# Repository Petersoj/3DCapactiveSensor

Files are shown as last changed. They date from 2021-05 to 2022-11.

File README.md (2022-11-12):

# 3DCapacitiveSensor

This project uses the STM32F072RB MCU on the 32F072BDISCOVERY board and a large "3D" capacitor to measure the XYZ coordinates of a user's hand in physical space so that a user can move/click a computer mouse without touching anything. This project was inspired by [this](https://www.youtube.com/watch?v=ikD_3Vemkf0) video.

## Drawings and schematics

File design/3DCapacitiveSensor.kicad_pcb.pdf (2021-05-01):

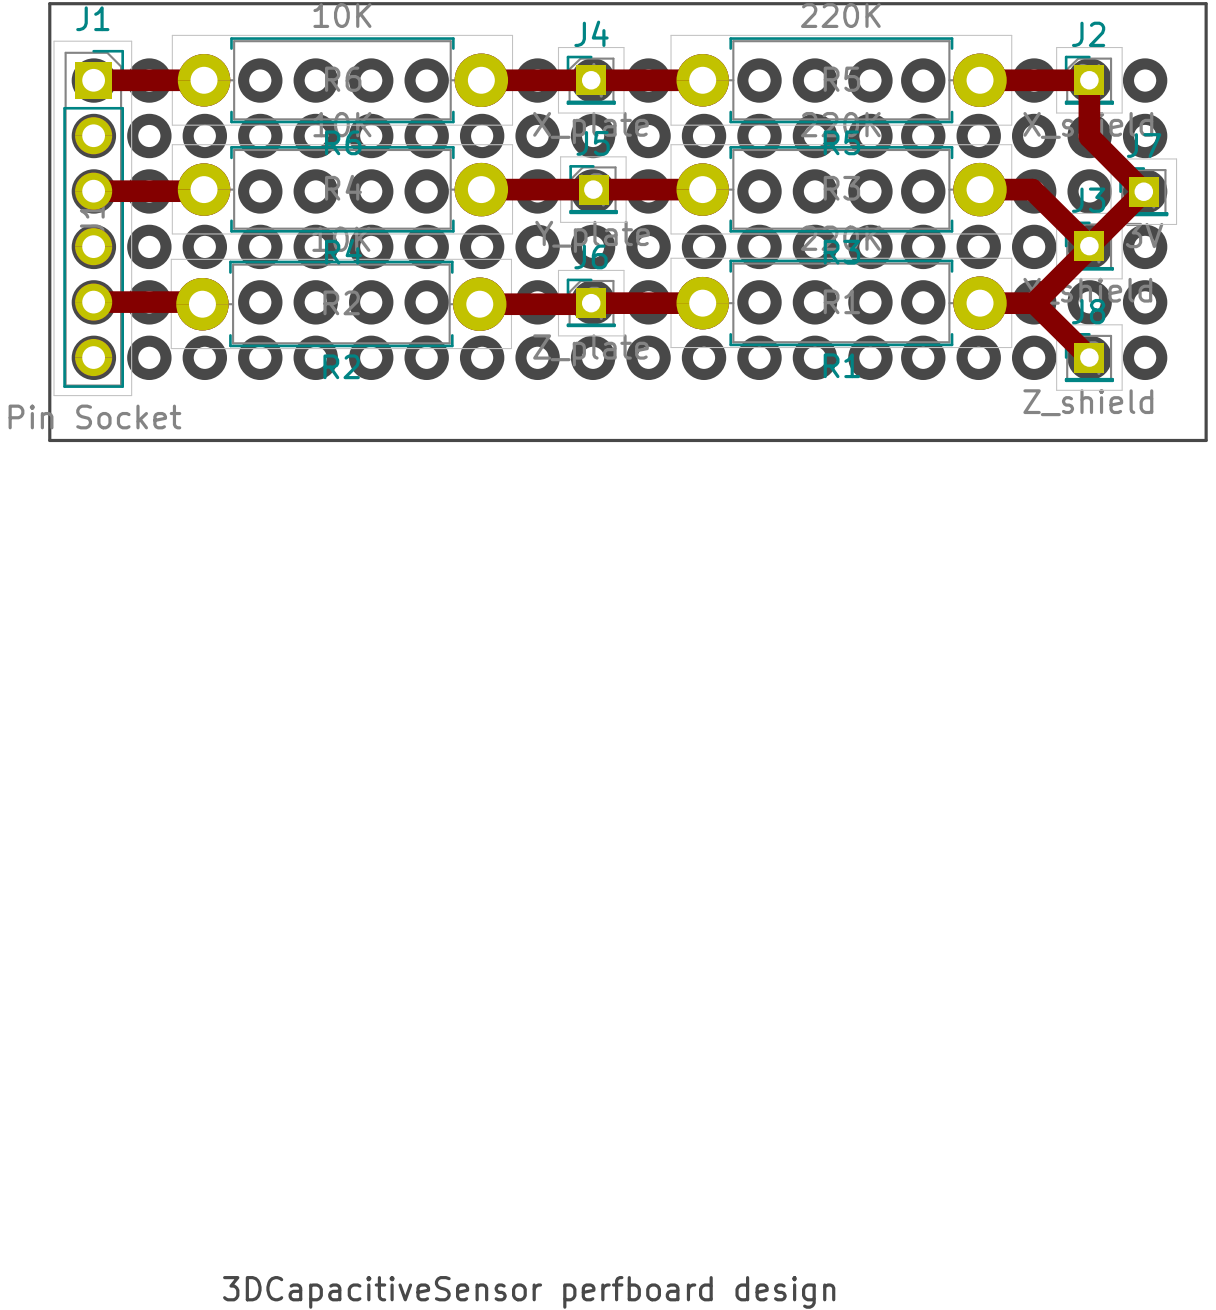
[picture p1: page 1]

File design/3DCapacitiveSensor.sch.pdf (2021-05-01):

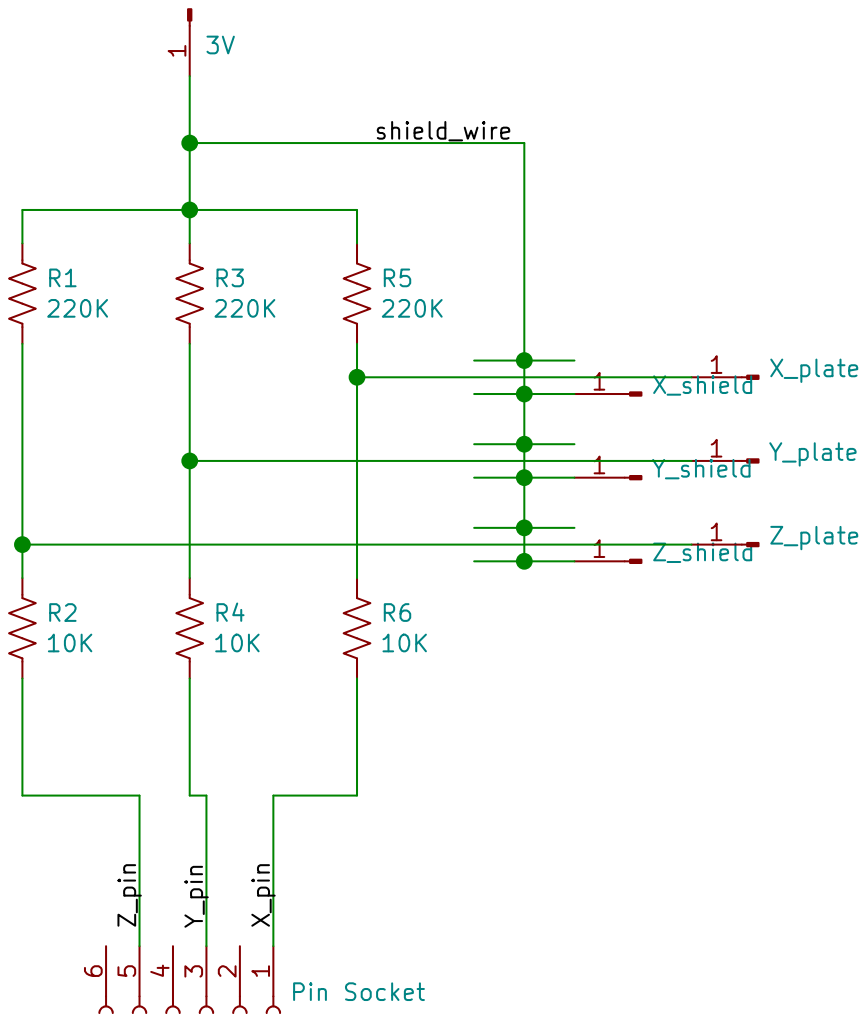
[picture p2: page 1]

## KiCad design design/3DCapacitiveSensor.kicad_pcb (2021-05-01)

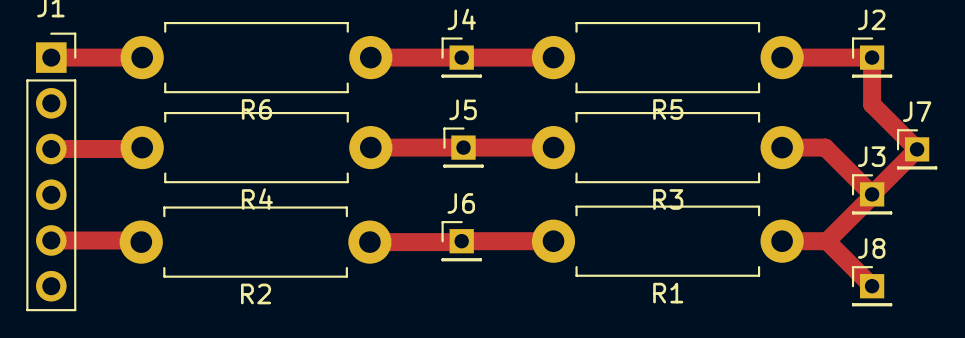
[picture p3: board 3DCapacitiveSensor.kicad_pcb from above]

Board: 2 copper layers, 14 parts (0 on the bottom side), 7 nets.

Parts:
J1: Pin Socket; PinSocket_1x06_P2.54mm_Vertical
J2: X_shield; PinHeader_1x01_P2.00mm_Vertical
J3: Y_shield; PinHeader_1x01_P2.00mm_Vertical
J4: X_plate; PinHeader_1x01_P2.00mm_Vertical
J5: Y_plate; PinHeader_1x01_P2.00mm_Vertical
J6: Z_plate; PinHeader_1x01_P2.00mm_Vertical
J7: 3V; PinHeader_1x01_P2.00mm_Vertical
J8: Z_shield; PinHeader_1x01_P2.00mm_Vertical
R1, R3, R5: 220K; R_Axial_DIN0411_L9.9mm_D3.6mm_P12.70mm_Horizontal
R2, R4, R6: 10K; R_Axial_DIN0411_L9.9mm_D3.6mm_P12.70mm_Horizontal

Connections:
/X_pin: J1.1, R6.2
/Y_pin: J1.3, R4.2
/Z_pin: J1.5, R2.2
/shield_wire: J2.1, J3.1, J7.1, J8.1, R1.1, R3.1, R5.1
unnamed: J4.1, R5.2, R6.1
unnamed: J5.1, R3.2, R4.1
unnamed: J6.1, R1.2, R2.1

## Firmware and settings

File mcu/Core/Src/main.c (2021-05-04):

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
/* Includes ------------------------------------------------------------------*/
#include "main.h"

/* USER CODE BEGIN Includes */

#define MOTOR_DRIVER

#ifdef MOTOR_DRIVER
#include "motor.h"
#endif

/* USER CODE END Includes */

/* USER CODE BEGIN PM */

#define USART3_BAUD_RATE 115200
#define MOTOR_DRIVER_MAX_RPM 10

/* USER CODE END PM */


/* USER CODE BEGIN PV */

char set_min_bool = 1;
char calibration_done = 0;
uint32_t plate_capacitance_min_counts[3] = {0};
uint32_t plate_capacitance_max_counts[3] = {0};

/* USER CODE END PV */

void SystemClock_Config(void);
/**
 * @brief  The application entry point.
 * @retval int
 */
int main(void) {
    /* MCU Configuration--------------------------------------------------------*/

    /* Reset of all peripherals, Initializes the Flash interface and the Systick. */
    HAL_Init();

    /* Configure the system clock */
    SystemClock_Config();

    /* Initialize all configured peripherals */
    /* USER CODE BEGIN 2 */

    // PINOUT:
    // PC6 = X Plate
    // PC7 = Y Plate
    // PC8 = Z Plate
    //
    // PC4 = STM32 TX / USB-UART RX
    // PC5 = STM32 RX / USB-UART TX
    //
    // Motor Driver Pinout:
    // ENCB = PB5
    // ENCA = PB4
    // IN2 = PA6
    // IN1 = PA5
    // ENABLE = PA4

    configure_rcc();
    configure_usart3_tx();
    motor_init();
    configure_gpio(GPIOC, 6);
    configure_gpio(GPIOC, 7);
    configure_gpio(GPIOC, 8);

    // Configure PA0 (User Button) as input
    // set_bits(&GPIOA->MODER, 0x0, GPIO_MODER_MODER0_Pos + 1, GPIO_MODER_MODER0_Pos);
    // set_bits(&GPIOA->PUPDR, 0x2, GPIO_PUPDR_PUPDR0_Pos + 1, GPIO_PUPDR_PUPDR0_Pos);
    RCC->AHBENR |= RCC_AHBENR_GPIOAEN; // Enable peripheral clock to GPIOA
    GPIOA->MODER &= ~(GPIO_MODER_MODER0_0 | GPIO_MODER_MODER0_1);           // Set PA0 to input
    GPIOC->OSPEEDR &= ~(GPIO_OSPEEDR_OSPEEDR0_0 | GPIO_OSPEEDR_OSPEEDR0_1); // Set to low speed
    GPIOC->PUPDR |= GPIO_PUPDR_PUPDR0_1;                                    // Set to pull-down

    uint8_t button_debouncer = 0;

    /* USER CODE END 2 */

    /* Infinite loop */
    /* USER CODE BEGIN WHILE */
    while (1) {
        /* USER CODE END WHILE */

        /* USER CODE BEGIN 3 */
        uint32_t x_capacitance = poll_capacitance(GPIOC, 6);
        uint32_t y_capacitance = poll_capacitance(GPIOC, 7);
        uint32_t z_capacitance = poll_capacitance(GPIOC, 8);

        uint8_t user_button = GPIOA->IDR & (1 << 0);
        if (user_button) {
            button_debouncer = 1;
        }
        if (button_debouncer == 1 && user_button == 0) {
            button_debouncer = 0;
            if (set_min_bool) {
                plate_capacitance_min_counts[0] = x_capacitance;
                plate_capacitance_min_counts[1] = y_capacitance;
                plate_capacitance_min_counts[2] = z_capacitance;
                set_min_bool = 0;
            } else {
                plate_capacitance_max_counts[0] = x_capacitance;
                plate_capacitance_max_counts[1] = y_capacitance;
                plate_capacitance_max_counts[2] = z_capacitance;

                char buffer[20];
                // Transmit formatted min and max to client
                usart3_transmit_string("min,");
                to_string(plate_capacitance_min_counts[0], buffer, 10);
                usart3_transmit_string(buffer);
                usart3_transmit_char(',');
                to_string(plate_capacitance_min_counts[1], buffer, 10);
                usart3_transmit_string(buffer);
                usart3_transmit_char(',');
                to_string(plate_capacitance_min_counts[2], buffer, 10);
                usart3_transmit_string(buffer);
                usart3_transmit_newline(CRLF);

                usart3_transmit_string("max,");
                to_string(plate_capacitance_max_counts[0], buffer, 10);
                usart3_transmit_string(buffer);
                usart3_transmit_char(',');
                to_string(plate_capacitance_max_counts[1], buffer, 10);
                usart3_transmit_string(buffer);
                usart3_transmit_char(',');
                to_string(plate_capacitance_max_counts[2], buffer, 10);
                usart3_transmit_string(buffer);
                usart3_transmit_newline(CRLF);

                set_min_bool = 1;
                calibration_done = 1;
            }
        }

        if (calibration_done) {
            // Transmit capacitance data
            char buffer[20];
            to_string(x_capacitance, buffer, 10);
            usart3_transmit_string(buffer);
            usart3_transmit_string(",");
            to_string(y_capacitance, buffer, 10);
            usart3_transmit_string(buffer);
            usart3_transmit_string(",");
            to_string(z_capacitance, buffer, 10);
            usart3_transmit_string(buffer);
            usart3_transmit_newline(CRLF);

#ifdef MOTOR_DRIVER
            // Update motor target RPM (use X plate)
            target_rpm = (x_capacitance - plate_capacitance_min_counts[0]) * MOTOR_DRIVER_MAX_RPM /
                         (plate_capacitance_max_counts[0] - plate_capacitance_min_counts[0]);
#endif
        }
    }
    /* USER CODE END 3 */
}

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
/* USER CODE BEGIN 4 */

void configure_rcc(void) {
    // Enable GPIOA clock
    set_bit(&RCC->AHBENR, 1, RCC_AHBENR_GPIOAEN_Pos);
    // Enable GPIOB clock
    set_bit(&RCC->AHBENR, 1, RCC_AHBENR_GPIOBEN_Pos);
    // Enable GPIOC clock
    set_bit(&RCC->AHBENR, 1, RCC_AHBENR_GPIOCEN_Pos);
    // Enable the USART3 clock
    set_bit(&RCC->APB1ENR, 1, RCC_APB1ENR_USART3EN_Pos);
}

void configure_usart3_tx(void) {
    // Configure PC4 for USART3 Alternate Function
    set_bits(&GPIOC->MODER, 0x2, GPIO_MODER_MODER4_Pos + 1, GPIO_MODER_MODER4_Pos);
    // Configure PC5 for USART3 Alternate Function
    set_bits(&GPIOC->MODER, 0x2, GPIO_MODER_MODER5_Pos + 1, GPIO_MODER_MODER5_Pos);

    // Configure PC4 Alternate Function (AF) Low Register for AF1
    set_bits(&GPIOC->AFR[0], 0x1, GPIO_AFRL_AFSEL4_Pos + 3, GPIO_AFRL_AFSEL4_Pos);
    // Configure PC5 Alternate Function (AF) Low Register for AF1
    set_bits(&GPIOC->AFR[0], 0x1, GPIO_AFRL_AFSEL5_Pos + 3, GPIO_AFRL_AFSEL5_Pos);

    // Set the baud rate of USART3
    set_bits(&USART3->BRR, HAL_RCC_GetHCLKFreq() / USART3_BAUD_RATE, 15, 0);
    // Enable USART3 TX
    set_bit(&USART3->CR1, 1, USART_CR1_TE_Pos);
    // Enable USART3
    set_bit(&USART3->CR1, 1, USART_CR1_UE_Pos);
}

void configure_gpio(GPIO_TypeDef *gpio_pointer, uint8_t gpio_number) {
    // High output speed
    set_bits(&gpio_pointer->OSPEEDR, 0x3, gpio_number * 2 + 1, gpio_number * 2); // 0x3 = 0b11
}

void gpio_pull_low(GPIO_TypeDef *gpio_pointer, uint8_t gpio_number) {
    // General purpose output mode
    set_bits(&gpio_pointer->MODER, 0x1, gpio_number * 2 + 1, gpio_number * 2);
    // Push-pull output type
    set_bit(&gpio_pointer->MODER, 0x0, gpio_number);
    // No pull-up, no pull-down resistors
    set_bits(&gpio_pointer->PUPDR, 0x0, gpio_number * 2 + 1, gpio_number * 2);
    // Output LOW
    set_bit(&gpio_pointer->BSRR, 0x1, gpio_number + 16);
}

void gpio_configure_input(GPIO_TypeDef *gpio_pointer, uint8_t gpio_number) {
    // Input mode
    set_bits(&gpio_pointer->MODER, 0x0, gpio_number * 2 + 1, gpio_number * 2);
    // No pull-up, no pull-down resistors
    set_bits(&gpio_pointer->PUPDR, 0x0, gpio_number * 2 + 1, gpio_number * 2);
}

uint8_t gpio_get_input(GPIO_TypeDef *gpio_pointer, uint8_t gpio_number) {
    // Get value from input data register
    return get_bit(&gpio_pointer->IDR, gpio_number);
}

uint32_t poll_capacitance(GPIO_TypeDef *gpio_pointer, uint8_t gpio_number) {
    int total = 0, count = 0;
    // This while loop is to average several low 'count' samples
    // to get a more accurate reading.
    while (total < 1000) {
        gpio_pull_low(gpio_pointer, gpio_number);        // Discharges plate capacitor
        gpio_configure_input(gpio_pointer, gpio_number); // Sets GPIO as high impedance
        // Loop until GPIO pin positive edge (plate capacitor charging)
        while (gpio_get_input(gpio_pointer, gpio_number) == 0) {
            count++;
        }
        total++;
    }
    return (count << 12) / total;
}

void usart3_transmit_char(char character) {
    // Busy wait while TX register is not empty
    while (get_bit(&USART3->ISR, USART_ISR_TXE_Pos) == 0) {
    }
    // Write 'character' to Transmit Data Register
    USART3->TDR = character;
}

void usart3_transmit_string(char string[]) {
    uint32_t index = 0;
    char character;
    // Transmit char until 0 is reached
    while ((character = string[index++]) != 0x0) {
        usart3_transmit_char(character);
    }
}

void usart3_transmit_newline(enum LineEnding lineEnding) {
    switch (lineEnding) {
        case CR:
            usart3_transmit_char('\r');
            break;
        case LF:
            usart3_transmit_char('\n');
            break;
        case CRLF:
            usart3_transmit_char('\r');
            usart3_transmit_char('\n');
            break;
    }
}

// (https://stackoverflow.com/a/23840699)
// Used instead of sprintf for performance.
char *to_string(int value, char *result, int base) {
    // Check that the base if valid
    if (base < 2 || base > 36) {
        *result = '\0';
        return result;
    }

    char *ptr = result, *ptr1 = result, tmp_char;
    int tmp_value;

    do {
        tmp_value = value;
        value /= base;
        *ptr++ = "zyxwvutsrqponmlkjihgfedcba9876543210123456789abcdefghijklmnopqrstuvwxyz"
            [35 + (tmp_value - value * base)];
    } while (value);

    // Apply negative sign
    if (tmp_value < 0)
        *ptr++ = '-';
    *ptr-- = '\0';
    while (ptr1 < ptr) {
        tmp_char = *ptr;
        *ptr-- = *ptr1;
        *ptr1++ = tmp_char;
    }
    return result;
}

static inline void set_bits(volatile uint32_t *to_set, uint32_t number, uint8_t msb, uint8_t lsb) {
    uint32_t temp = *to_set;
    uint32_t mask = (~0u << (msb + 1)) | ~(~0u << lsb);
    temp |= ~mask & (number << lsb);
    temp &= mask | (number << lsb);
    *to_set = temp;
}

static inline void set_bit(volatile uint32_t *to_set, uint32_t bit, uint8_t index) {
    set_bits(to_set, bit, index, index);
}

static inline uint32_t get_bits(volatile uint32_t *to_get, uint8_t msb, uint8_t lsb) {
    uint32_t mask = ~((~0u << (msb + 1)) | ~(~0u << lsb));
    return (*to_get & mask) >> lsb;
}

static inline uint32_t get_bit(volatile uint32_t *to_get, uint8_t index) {
    return get_bits(to_get, index, index);
}

/* USER CODE END 4 */
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


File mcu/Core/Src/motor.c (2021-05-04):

/* -------------------------------------------------------------------------------------------------------------
 *  Motor Control and Initialization Functions
 * -------------------------------------------------------------------------------------------------------------
 */
#include "motor.h"

volatile int16_t error_integral = 0; // Integrated error signal
volatile uint8_t duty_cycle = 0;     // Output PWM duty cycle
volatile int16_t target_rpm = 0;     // Desired speed target
volatile int16_t motor_speed = 0;    // Measured motor speed
volatile int8_t adc_value = 0;       // ADC measured motor current
volatile int16_t error = 0;          // Speed error signal
volatile uint8_t Kp = 1;             // Proportional gain
volatile uint8_t Ki = 1;             // Integral gain

// Sets up the entire motor drive system
void motor_init(void) {
    pwm_init();
    encoder_init();
    ADC_init();
}

// Sets up the PWM and direction signals to drive the H-Bridge
void pwm_init(void) {

    // Set up pin PA4 for H-bridge PWM output (TIMER 14 CH1)
    GPIOA->MODER |= (1 << 9);
    GPIOA->MODER &= ~(1 << 8);

    // Set PA4 to AF4,
    GPIOA->AFR[0] &= 0xFFF0FFFF; // clear PA4 bits,
    GPIOA->AFR[0] |= (1 << 18);

    // Set up a PA5, PA6 as GPIO output pins for motor direction control
    GPIOA->MODER &= 0xFFFFC3FF; // clear PA5, PA6 bits,
    GPIOA->MODER |= (1 << 10) | (1 << 12);

    // Initialize one direction pin to high, the other low
    GPIOA->ODR |= (1 << 5);
    GPIOA->ODR &= ~(1 << 6);

    // Set up PWM timer
    RCC->APB1ENR |= RCC_APB1ENR_TIM14EN;
    TIM14->CR1 = 0;   // Clear control registers
    TIM14->CCMR1 = 0; // (prevents having to manually clear bits)
    TIM14->CCER = 0;

    // Set output-compare CH1 to PWM1 mode and enable CCR1 preload buffer
    TIM14->CCMR1 |= (TIM_CCMR1_OC1M_2 | TIM_CCMR1_OC1M_1 | TIM_CCMR1_OC1PE);
    TIM14->CCER |= TIM_CCER_CC1E; // Enable capture-compare channel 1
    TIM14->PSC = 1;               // Run timer on 24Mhz
    TIM14->ARR = 1200;            // PWM at 20kHz
    TIM14->CCR1 = 0;              // Start PWM at 0% duty cycle

    TIM14->CR1 |= TIM_CR1_CEN; // Enable timer
}

// Set the duty cycle of the PWM, accepts (0-100)
void pwm_setDutyCycle(uint8_t duty) {
    if (duty <= 100) {
        TIM14->CCR1 =
            ((uint32_t)duty * TIM14->ARR) / 100; // Use linear transform to produce CCR1 value
        // (CCR1 == "pulse" parameter in PWM struct used by peripheral library)
    }
}

// Sets up encoder interface to read motor speed
void encoder_init(void) {

    // Set up encoder input pins (TIMER 3 CH1 and CH2)
    RCC->AHBENR |= RCC_AHBENR_GPIOBEN;

    GPIOB->MODER &= ~(GPIO_MODER_MODER4_0 | GPIO_MODER_MODER5_0);
    GPIOB->MODER |= (GPIO_MODER_MODER4_1 | GPIO_MODER_MODER5_1);
    GPIOB->AFR[0] |= ((1 << 16) | (1 << 20));

    // Set up encoder interface (TIM3 encoder input mode)
    RCC->APB1ENR |= RCC_APB1ENR_TIM3EN;
    TIM3->CCMR1 = 0;
    TIM3->CCER = 0;
    TIM3->SMCR = 0;
    TIM3->CR1 = 0;

    TIM3->CCMR1 |=
        (TIM_CCMR1_CC1S_0 | TIM_CCMR1_CC2S_0); // TI1FP1 and TI2FP2 signals connected to CH1 and CH2
    TIM3->SMCR |=
        (TIM_SMCR_SMS_1 | TIM_SMCR_SMS_0); // Capture encoder on both rising and falling edges
    TIM3->ARR = 0xFFFF;                    // Set ARR to top of timer (longest possible period)
    TIM3->CNT = 0x7FFF;                    // Bias at midpoint to allow for negative rotation
    // (Could also cast unsigned register to signed number to get negative numbers if it rotates
    // backwards past zero
    //  just another option, the mid-bias is a bit simpler to understand though.)
    TIM3->CR1 |= TIM_CR1_CEN; // Enable timer

    // Configure a second timer (TIM6) to fire an ISR on update event
    // Used to periodically check and update speed variable
    RCC->APB1ENR |= RCC_APB1ENR_TIM6EN;

    // Select PSC and ARR values that give an appropriate interrupt rate
    TIM6->PSC = 15;
    TIM6->ARR = 50000 / 2;

    TIM6->DIER |= TIM_DIER_UIE; // Enable update event interrupt
    TIM6->CR1 |= TIM_CR1_CEN;   // Enable Timer

    NVIC_EnableIRQ(TIM6_DAC_IRQn); // Enable interrupt in NVIC
    NVIC_SetPriority(TIM6_DAC_IRQn, 2);
}

// Encoder interrupt to calculate motor speed, also manages PI controller
void TIM6_DAC_IRQHandler(void) {
    /* Calculate the motor speed in raw encoder counts
     * Note the motor speed is signed! Motor can be run in reverse.
     * Speed is measured by how far the counter moved from center point
     */
    motor_speed = (TIM3->CNT - 0x7FFF);
    TIM3->CNT = 0x7FFF; // Reset back to center point

    // Call the PI update function
    PI_update();

    TIM6->SR &= ~TIM_SR_UIF; // Acknowledge the interrupt
}

void ADC_init(void) {

    // Configure PA1 for ADC input (used for current monitoring)
    GPIOA->MODER |= (GPIO_MODER_MODER1_0 | GPIO_MODER_MODER1_1);

    // Configure ADC to 8-bit continuous-run mode, (asynchronous clock mode)
    RCC->APB2ENR |= RCC_APB2ENR_ADCEN;

    ADC1->CFGR1 = 0;                   // Default resolution is 12-bit (RES[1:0] = 00 --> 12-bit)
    ADC1->CFGR1 |= ADC_CFGR1_CONT;     // Set to continuous mode
    ADC1->CHSELR |= ADC_CHSELR_CHSEL1; // Enable channel 1

    ADC1->CR = 0;
    ADC1->CR |= ADC_CR_ADCAL; // Perform self calibration
    while (ADC1->CR & ADC_CR_ADCAL)
        ; // Delay until calibration is complete

    ADC1->CR |= ADC_CR_ADEN; // Enable ADC
    while (!(ADC1->ISR & ADC_ISR_ADRDY))
        ;                       // Wait until ADC ready
    ADC1->CR |= ADC_CR_ADSTART; // Signal conversion start
}
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

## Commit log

2021-04-10 Add schematic and board layout
    [3DCapacitiveSensor.kicad_pcb, 3DCapacitiveSensor.sch]
2021-04-15 Add initial uVision project for STM32 DiscoveryBoard
2021-04-15 Add initial testing code for UART communication
2021-05-01 Update schematic
    [3DCapacitiveSensor.kicad_pcb, 3DCapacitiveSensor.sch]
2021-05-01 Add usart3 TX, configure rcc, and adc/gpio functions
2021-05-01 Add function prototypes and add ADC wait mode
2021-05-01 Fix ADC function bugs and add testing code
    [main.c]
2021-05-02 Replace counting from ADC to Schmitt trigger GPIO
    [main.c]
2021-05-02 Use timer peripheral for capacitance level counting
2021-05-03 Revert to GPIO counting (can't get timer peripheral working)
    [main.c]
2021-05-03 Modify serial data format (X plate capacitor works now)
2021-05-04 Add motor driver code from Lab 7 and adapt it for x-plate speed control

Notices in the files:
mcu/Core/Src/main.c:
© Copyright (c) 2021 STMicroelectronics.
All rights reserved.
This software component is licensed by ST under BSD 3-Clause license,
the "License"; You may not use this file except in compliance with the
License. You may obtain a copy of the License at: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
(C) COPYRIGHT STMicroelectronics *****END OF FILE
